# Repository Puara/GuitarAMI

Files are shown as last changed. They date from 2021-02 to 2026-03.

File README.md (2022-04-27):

# GuitarAMI

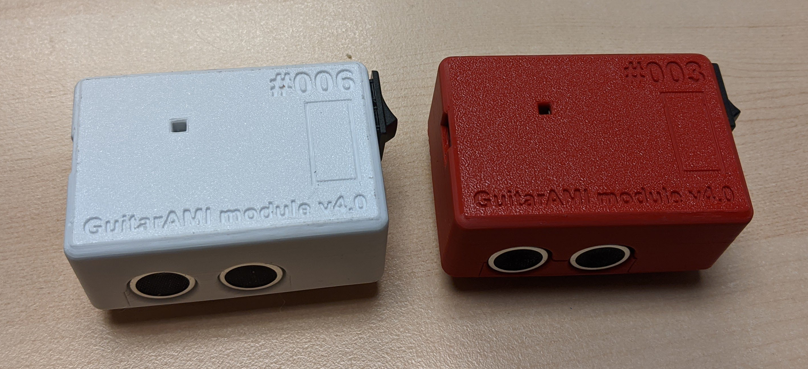
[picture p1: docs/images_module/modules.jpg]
Modules


The GuitarAMI is an Augmented Musical Instrument (AMI) using an acoustic guitar. The AMI is part of the [Puara](https://github.com/Puara) framework.

[GuitarAMI module - user guide](./docs/Module_user_guide.md)

## Building instructions

[GuitarAMI module](./docs/building_instructions_guitar_module.md)

## Description

Acoustic musical instruments, although very versatile, have intrinsic sonic limitations due to their construction characteristics. For the classical nylon strings guitar, these restrictions include short sustain and the lack of sound intensity control after the attack.

The GuitarAMI uses sensors installed non-invasively in classical guitars to generate data from gestures that control algorithms to overcome these limitations, providing new possibilities of expression for the performer.

### More Info on the instrument and the research

[https://www.edumeneses.com](https://www.edumeneses.com)

[http://www-new.idmil.org/project/guitarami/](http://www-new.idmil.org/project/guitarami/)

## Licensing

The code in this project is licensed under the MIT license, unless otherwise specified within the file.

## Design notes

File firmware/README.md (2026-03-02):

# OSC-Send

This template demonstrates how to use Puara modules to send OSC messages from the device.

Please refer to CNMAT's OSC repository on Github for more details on OSC.

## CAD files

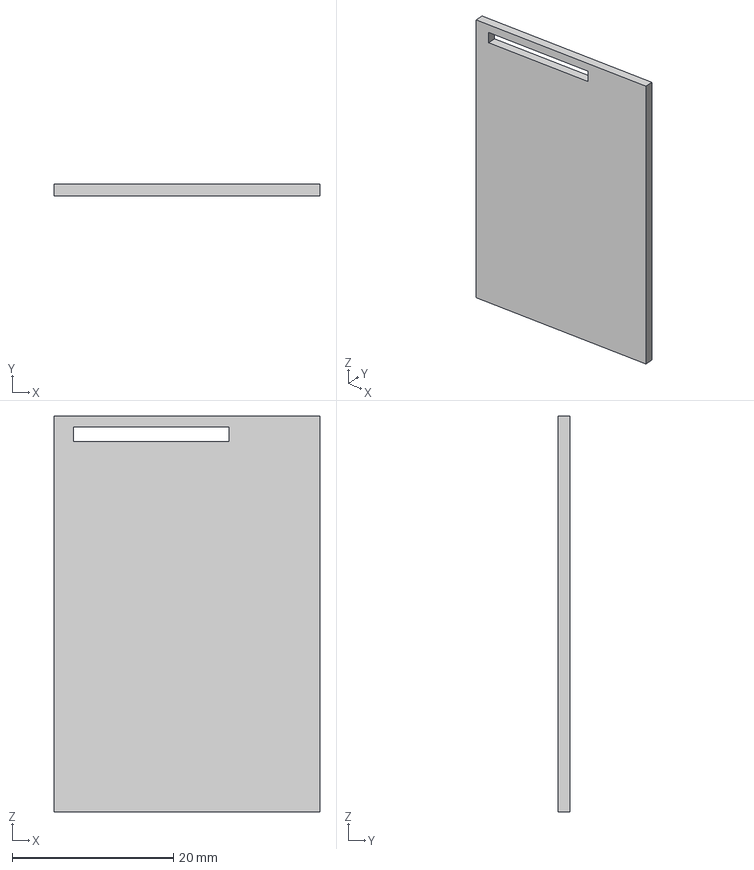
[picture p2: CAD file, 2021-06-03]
3D_printed_enclosure/GuitarAMI_module_XXX_TinyPICO_RCWL1601_battery_bed_top.step
33.0 x 1.50 x 49.1 mm

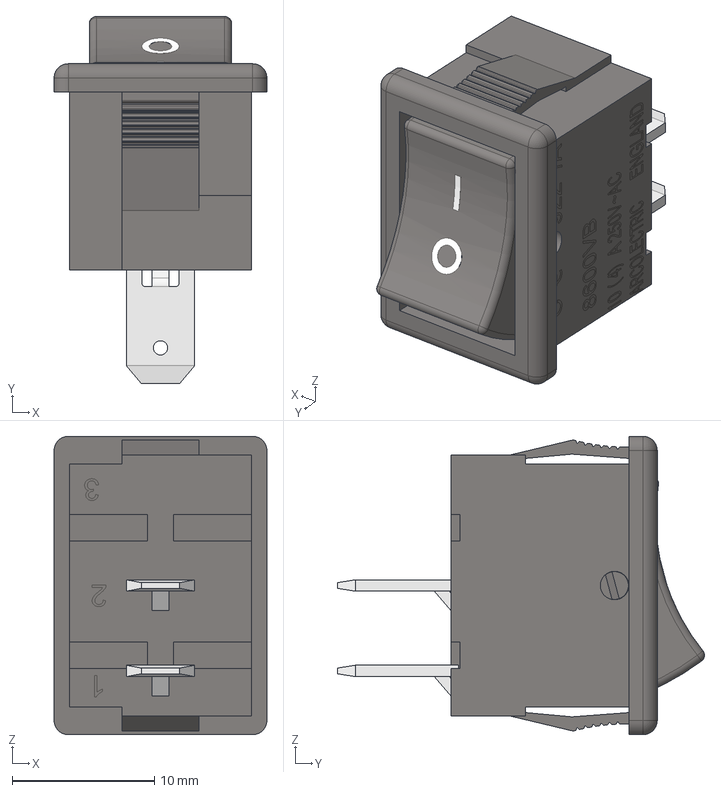
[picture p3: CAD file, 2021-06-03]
3D_printed_enclosure/parts/H8600V.step
14.9 x 25.8 x 20.9 mm
Housing
Rocker
Terminal x 2

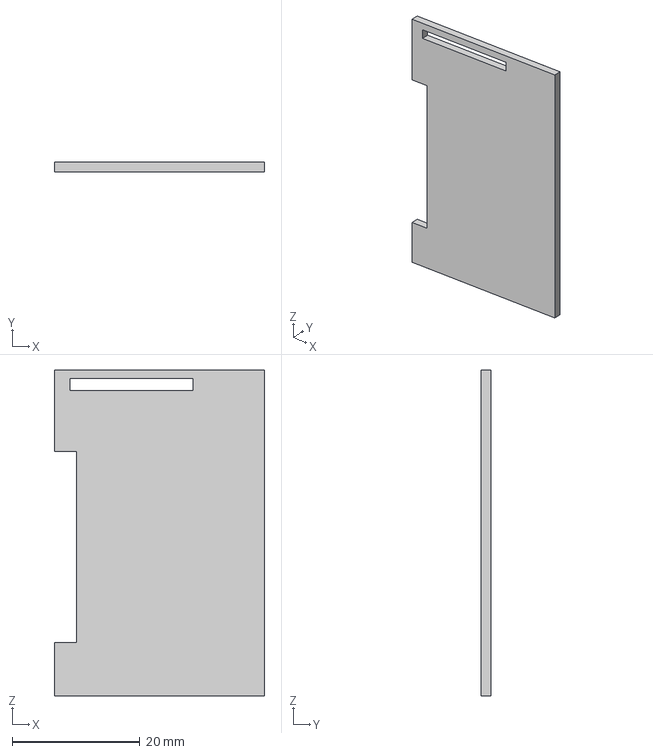
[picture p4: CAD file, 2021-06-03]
3D_printed_enclosure/GuitarAMI_module_XXX_TinyPICO_RCWL1601_battery_bed_bottom.step
33.0 x 1.50 x 51.1 mm

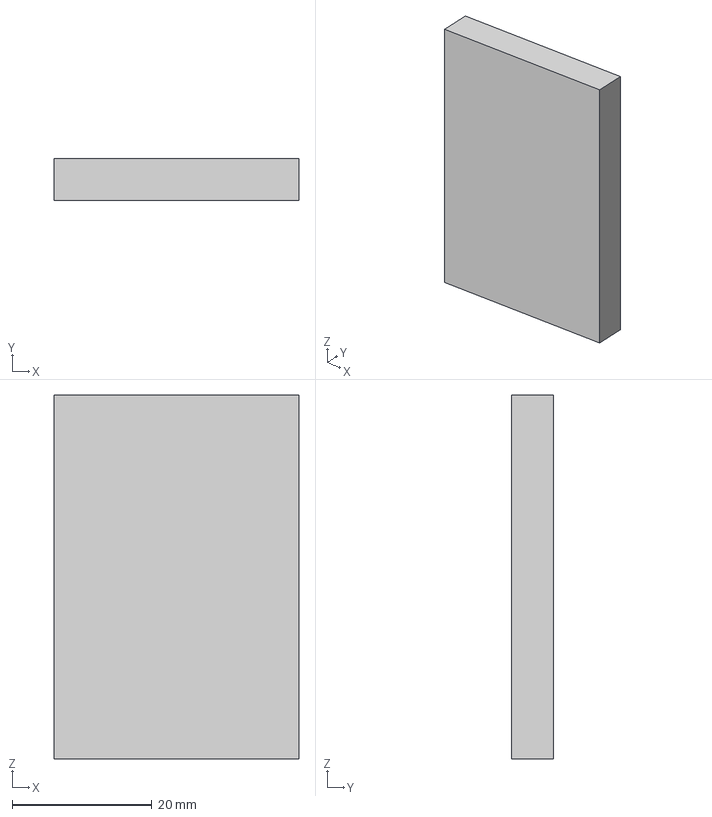
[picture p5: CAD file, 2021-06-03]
3D_printed_enclosure/parts/battery.step
35.0 x 6.00 x 52.0 mm

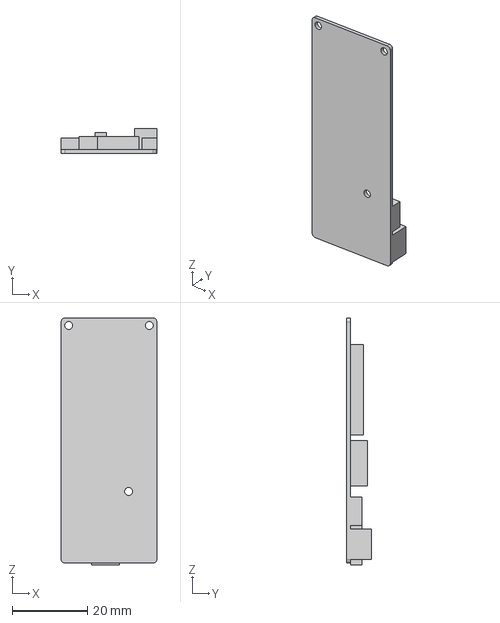
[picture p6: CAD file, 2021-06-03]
3D_printed_enclosure/parts/Wemos D32 Pro.step
25.4 x 6.50 x 65.5 mm

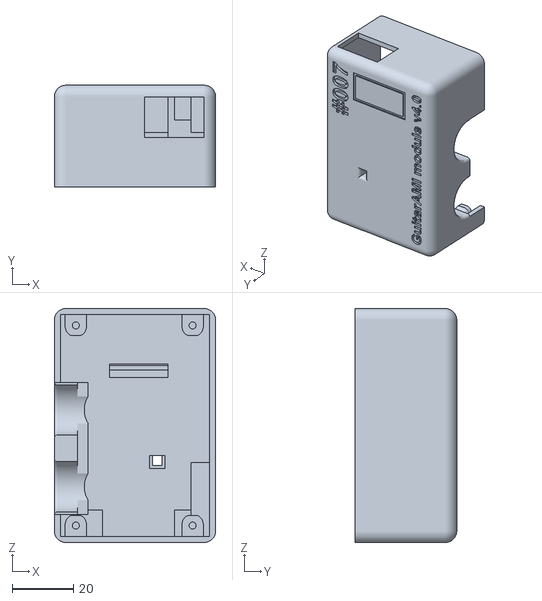
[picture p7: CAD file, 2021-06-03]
3D_printed_enclosure/GuitarAMI_module_007_TinyPICO_HCSR04+_box_top.stl
52.5 x 33.1 x 76.1

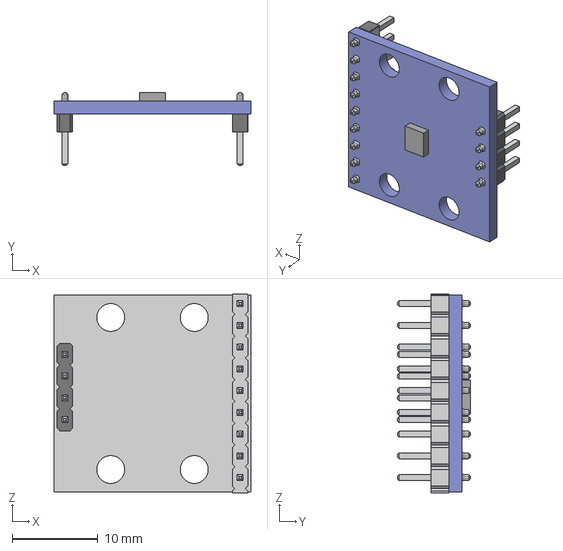
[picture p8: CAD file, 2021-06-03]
3D_printed_enclosure/parts/LSM9DS1.step
23.0 x 8.55 x 23.2 mm

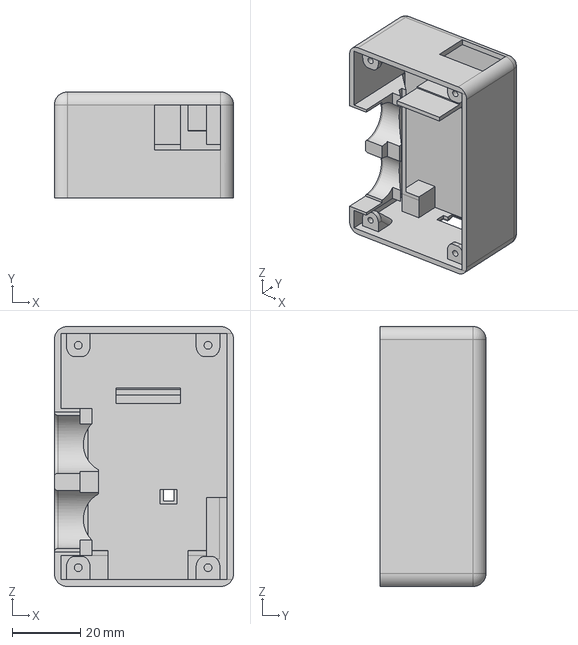
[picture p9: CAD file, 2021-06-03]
3D_printed_enclosure/GuitarAMI_module_XXX_TinyPICO_RCWL1601_box_top.step
52.5 x 31.1 x 76.1 mm

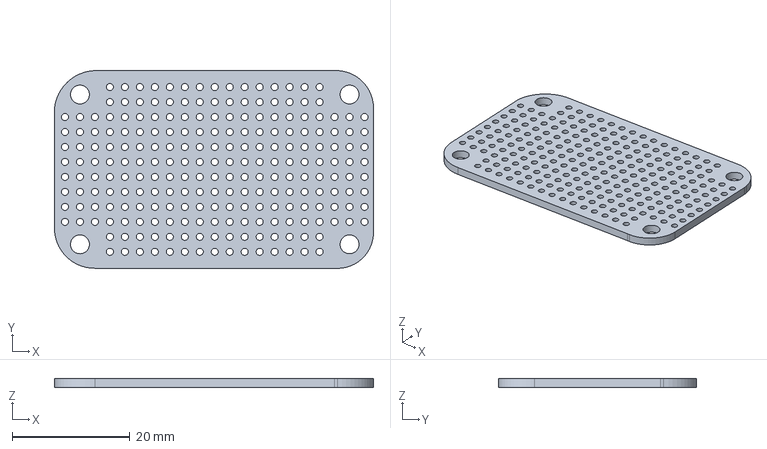
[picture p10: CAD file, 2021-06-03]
3D_printed_enclosure/parts/adafruit permaproto smalls.step
54.1 x 33.5 x 1.50 mm
Board
ALTOIDSSMALLS

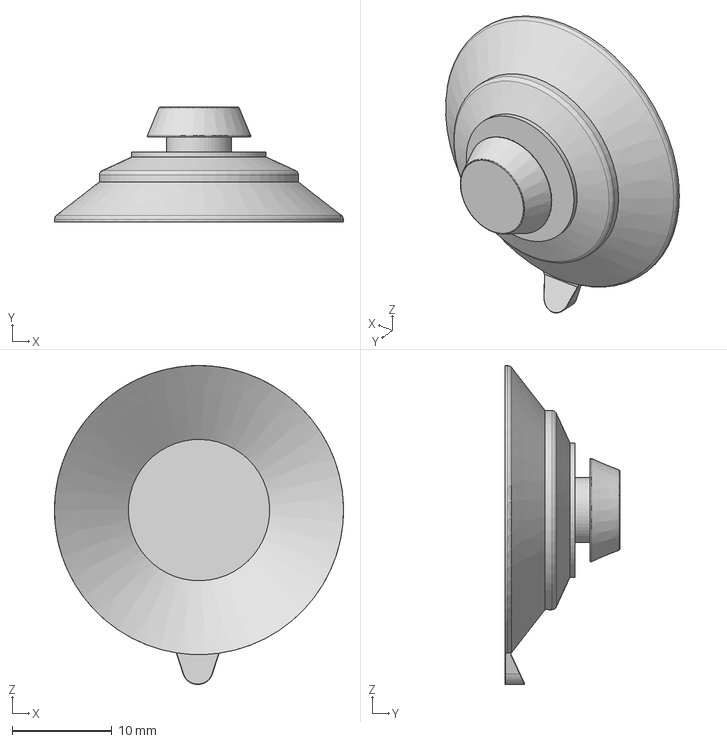
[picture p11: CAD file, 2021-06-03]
3D_printed_enclosure/parts/suction_cup_S-17647.step
29.0 x 11.5 x 32.0 mm

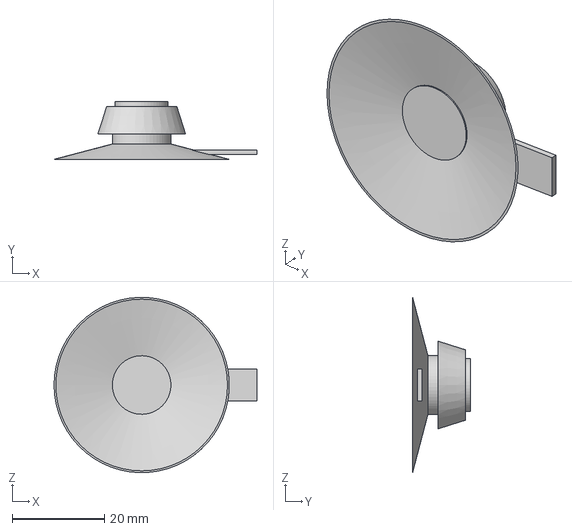
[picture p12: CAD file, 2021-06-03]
3D_printed_enclosure/parts/suction_cup_gitano.step
44.0 x 12.5 x 38.0 mm

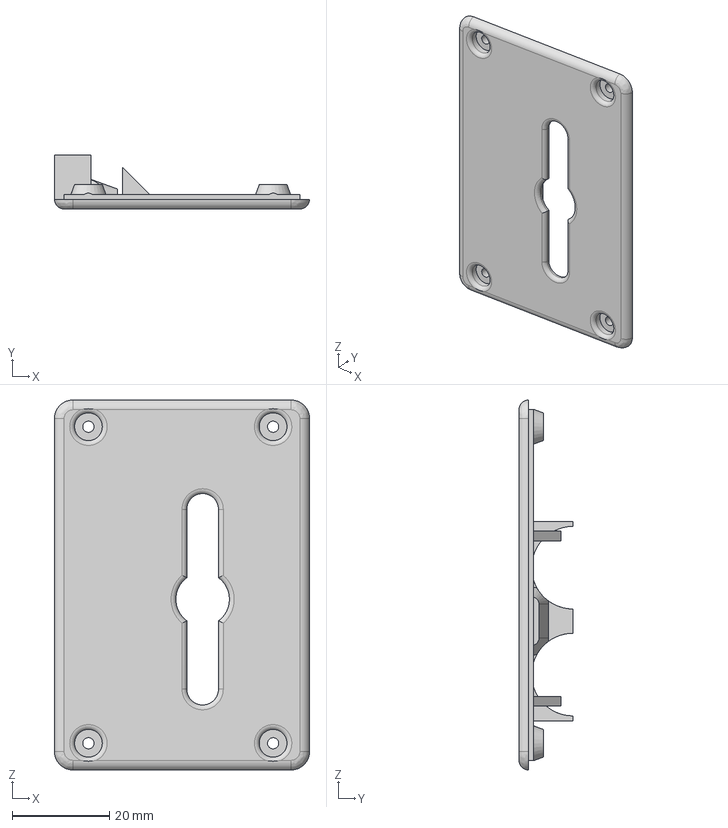
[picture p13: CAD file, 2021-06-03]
3D_printed_enclosure/GuitarAMI_module_XXX_TinyPICO_RCWL1601_box_bottom.step
52.5 x 11.1 x 76.1 mm

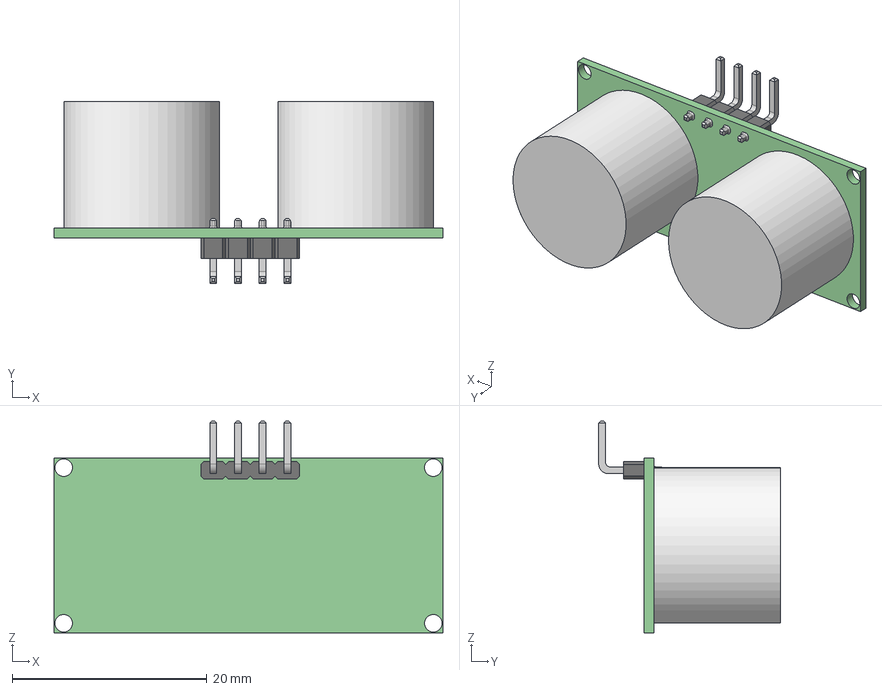
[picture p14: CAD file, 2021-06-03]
3D_printed_enclosure/parts/RCWL1601.step
40.0 x 18.7 x 21.8 mm

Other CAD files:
3D_printed_enclosure/GuitarAMI_module_XXX_TinyPICO_HCSR04+_battery_bed_bottom.stl
3D_printed_enclosure/GuitarAMI_module_003_TinyPICO_RCWL1601_box_top.stl
3D_printed_enclosure/GuitarAMI_module_006_TinyPICO_RCWL1601_box_top.stl
3D_printed_enclosure/GuitarAMI_module_005_TinyPICO_RCWL1601_box_top.stl
3D_printed_enclosure/GuitarAMI_module_XXX_TinyPICO_HCSR04+_battery_bed_top.stl
3D_printed_enclosure/GuitarAMI_module_XXX_TinyPICO_HCSR04+_box_bottom.stl
3D_printed_enclosure/GuitarAMI_module_XXX_TinyPICO_RCWL1601_battery_bed_bottom.stl
3D_printed_enclosure/GuitarAMI_module_XXX_TinyPICO_RCWL1601_battery_bed_top.stl
3D_printed_enclosure/GuitarAMI_module_XXX_TinyPICO_RCWL1601_box_bottom.stl
3D_printed_enclosure/GuitarAMI_module_XXX_TinyPICO_RCWL1601_box_top.stl

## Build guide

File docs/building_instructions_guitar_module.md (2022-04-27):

# How to build: GuitarAMI guitar module

## BOM

| Qty | Description | Online Reference |
| --- |:---|:--- |
| 1 | Rocker Switch | https://www.digikey.ca/en/products/detail/bulgin/H8600VBACN/9598449 |
| 1 | Small Suction Cups without Hooks | https://www.uline.ca/Product/Detail/S-17647/Store-Supplies/Suction-Cups-without-Hooks-Small |
| 1 | Perma-Proto Small Mint Tin Size Breadboard PCB | https://www.adafruit.com/product/1214 |
| 1 | Ultrasonic Distance Sensor - 3V compatible - RCWL-1601 | https://www.adafruit.com/product/4007 |
| 1 | TinyPICO - ESP32 Development Board | https://www.adafruit.com/product/4335 |
| 1 | 3.7V 2000mAh LiPo Rechargeable Battery | https://www.adafruit.com/product/2011 |
| 1 | LSM9DS1 nine-axis Sensor Module 9-axis IMU | https://www.sparkfun.com/products/13284 |

## Instructions

Start with the Perma-Proto Breadboard and solder all required connections according to the picture.

The IMU uses I2C, and it will be connected on rows 11-14 (breadboard) pins.
The TinyPico I2C (SDA and SCL) connections will be soldered on rows 3 and 2 of the breadboard (opposite side).

The ultrasonic sensor trigger and echo will be connected on rows 9 and 8 on the breadboard.
The TinyPico pins for that will be connected on rows 4 and 5 on the breadboard (same side).

The remaining jumper wires are for VCC and ground.

> :warning: **The TinyPico cannot reliably provide 5V when powered from battery**: Make sure the chosen ultrasonic sensor operates with 3.3V!

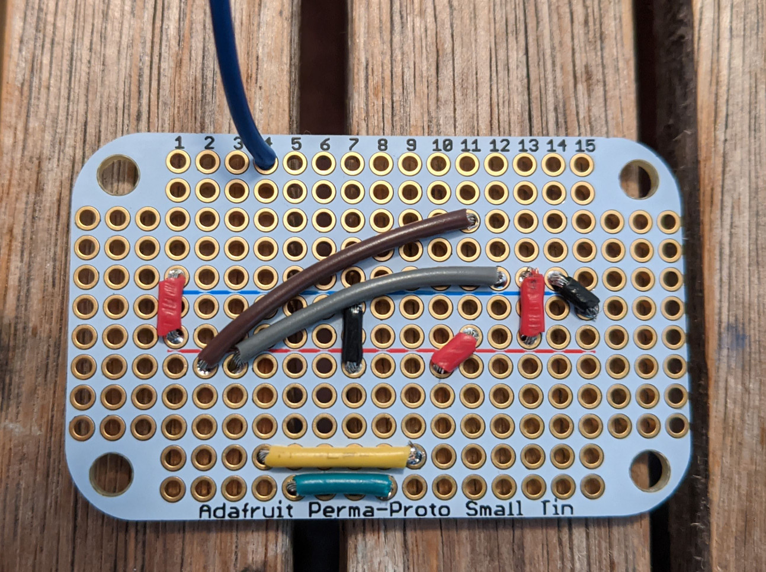
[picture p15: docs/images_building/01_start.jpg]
Start


Proceed by soldering the IMU:

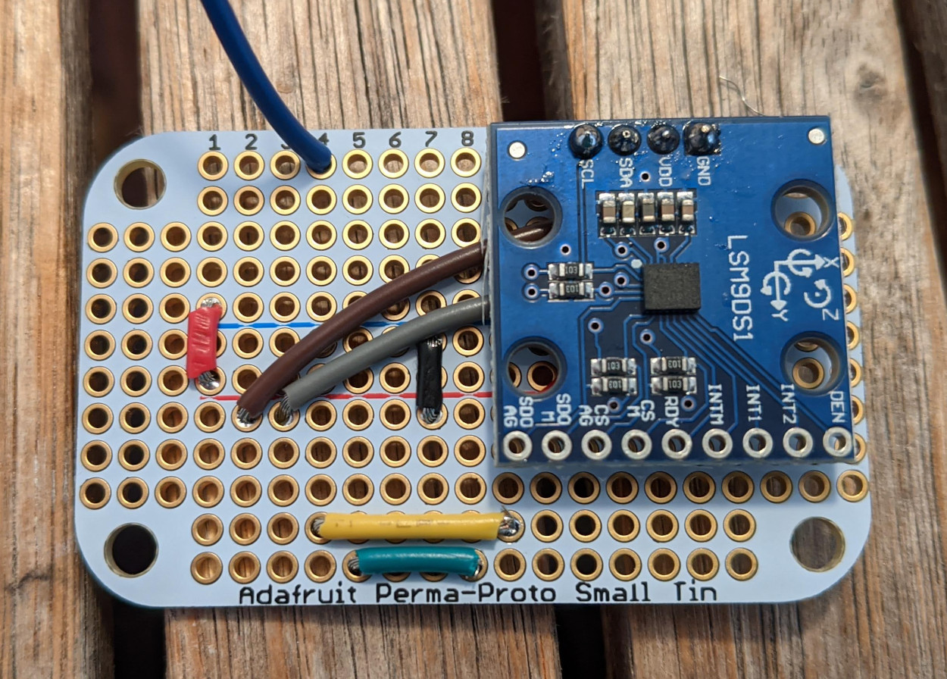
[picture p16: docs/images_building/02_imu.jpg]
IMU


Then the ultrasonic sensor. Note that the sensor is soldered "upside down".

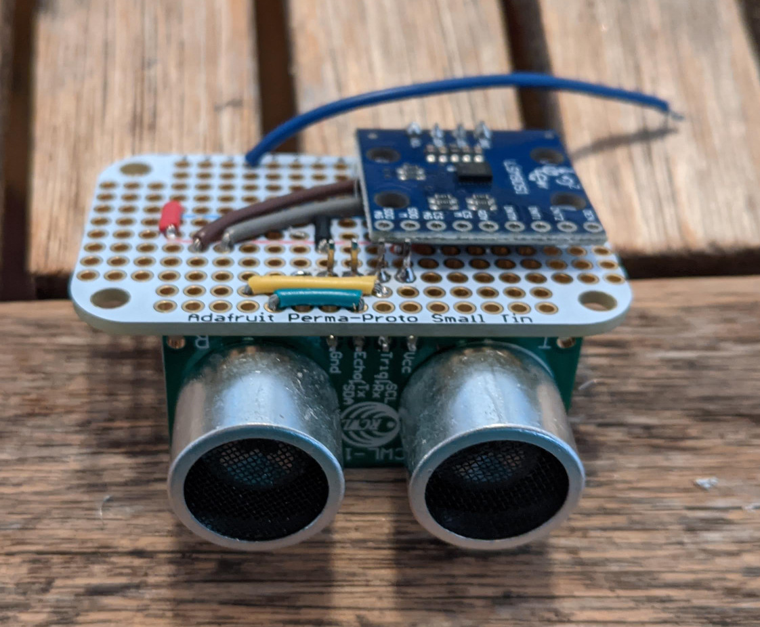
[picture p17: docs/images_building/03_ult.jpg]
Ultrasonic


Start preparing the TinyPico: set the header pins according to the picture below:

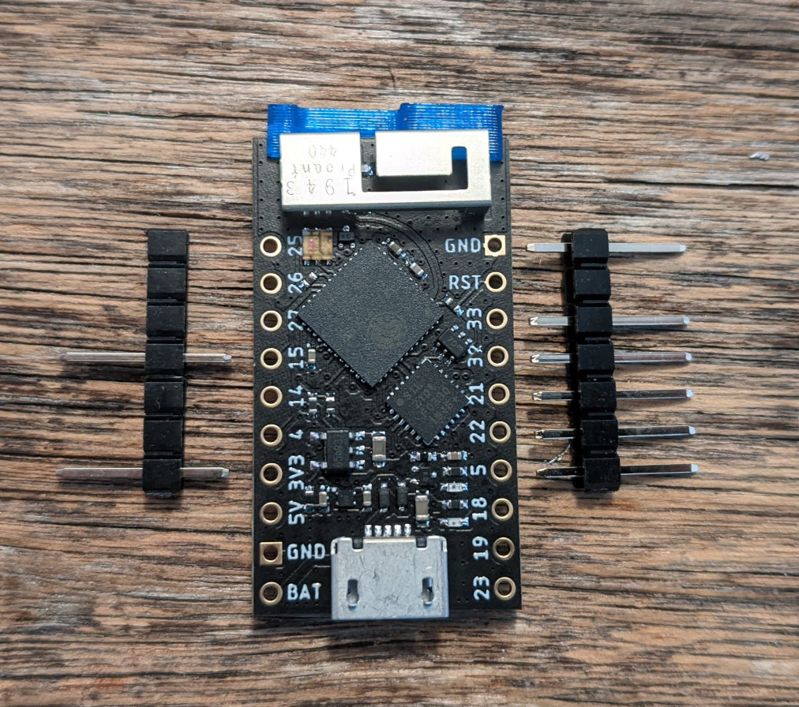
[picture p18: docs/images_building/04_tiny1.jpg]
TinyPico part 1 Tiny Pico part 1


Solder the pins on the TinyPico...

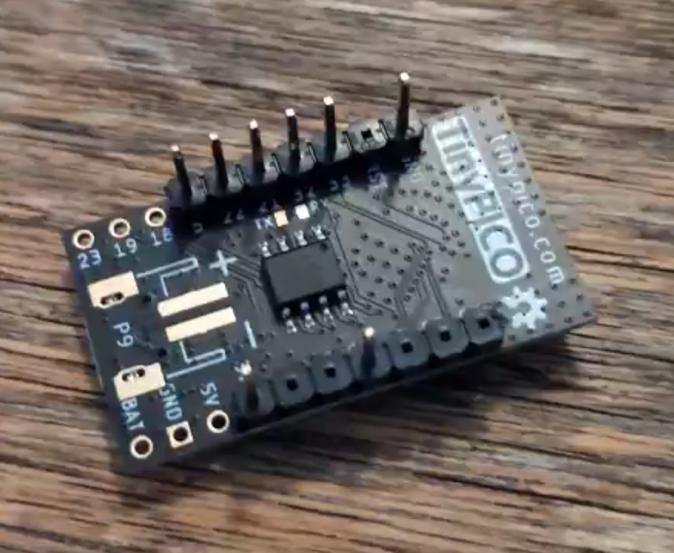
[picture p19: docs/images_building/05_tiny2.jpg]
TinyPico part 2 Tiny Pico part 2


... and the TinyPico to the breadboard according to the picture below.
Note that the USB connector must be aligned with the end of the breadboard.
That means some overlapping with the IMU is required.

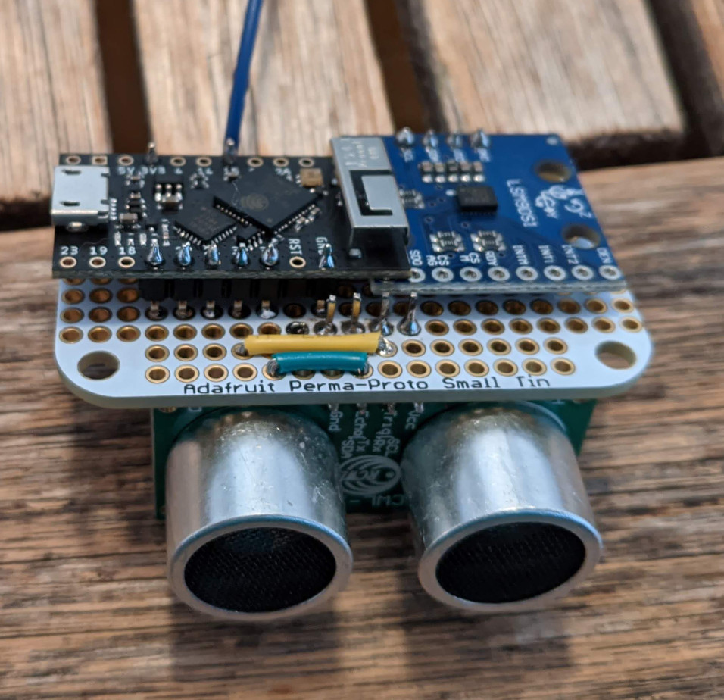
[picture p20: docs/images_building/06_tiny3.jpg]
TinyPico part 3 Tiny Pico part 3


Start preparing the touch sensor: a piece of copper tape and some wiring:

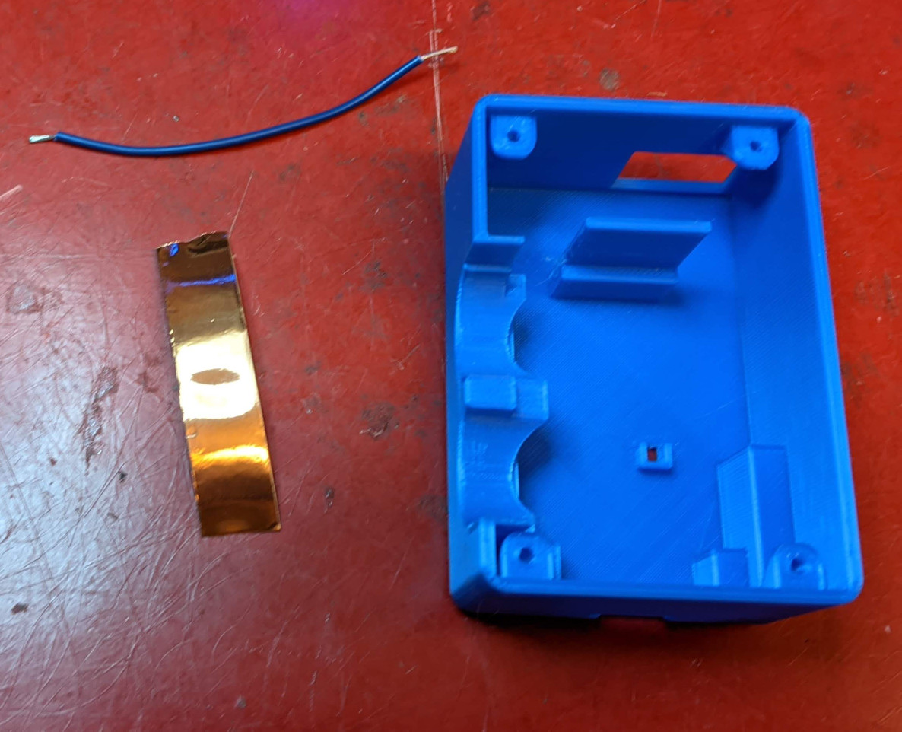
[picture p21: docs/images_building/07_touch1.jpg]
Touch part 1


Tape and solder according to the picture:

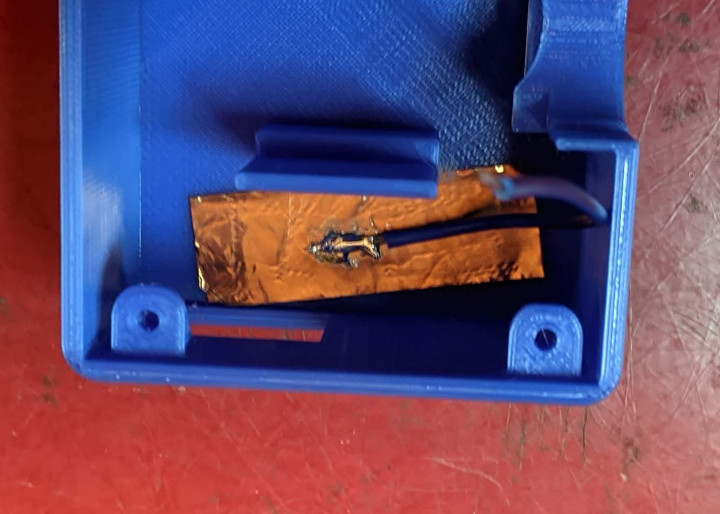
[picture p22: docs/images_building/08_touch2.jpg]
Touch part 2


Protect the copper tape to prevent sensor acquisition problems:

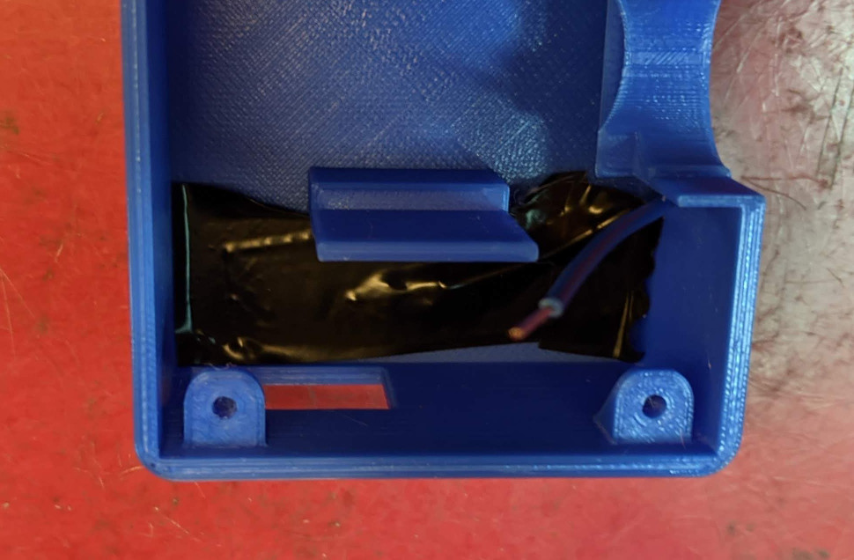
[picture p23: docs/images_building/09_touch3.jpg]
Touch part 3


Lastly, prepare the rocker switch:

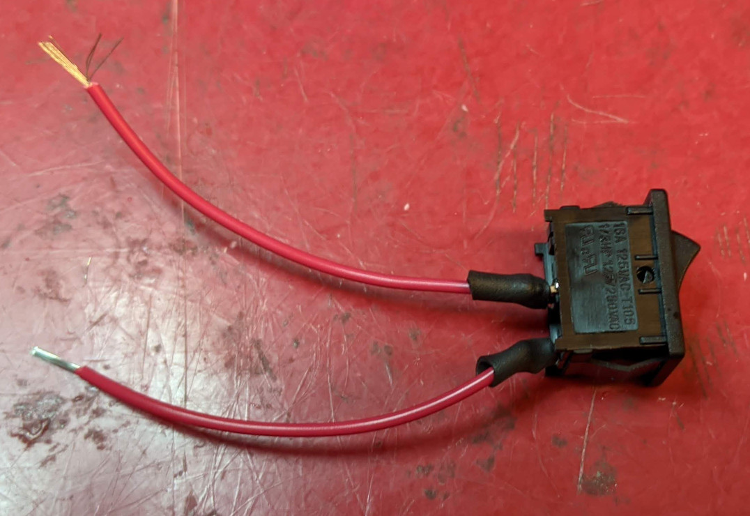
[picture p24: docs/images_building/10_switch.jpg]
Rocker Switch


Add the 3D printed enclosure and assemble everything together according to the pictures below.
The battery caps protect the breadboard and battery, and it is recommended to use the bottom cap.
The top cap can be used to prevent the battery to shake inside the module, if needed.

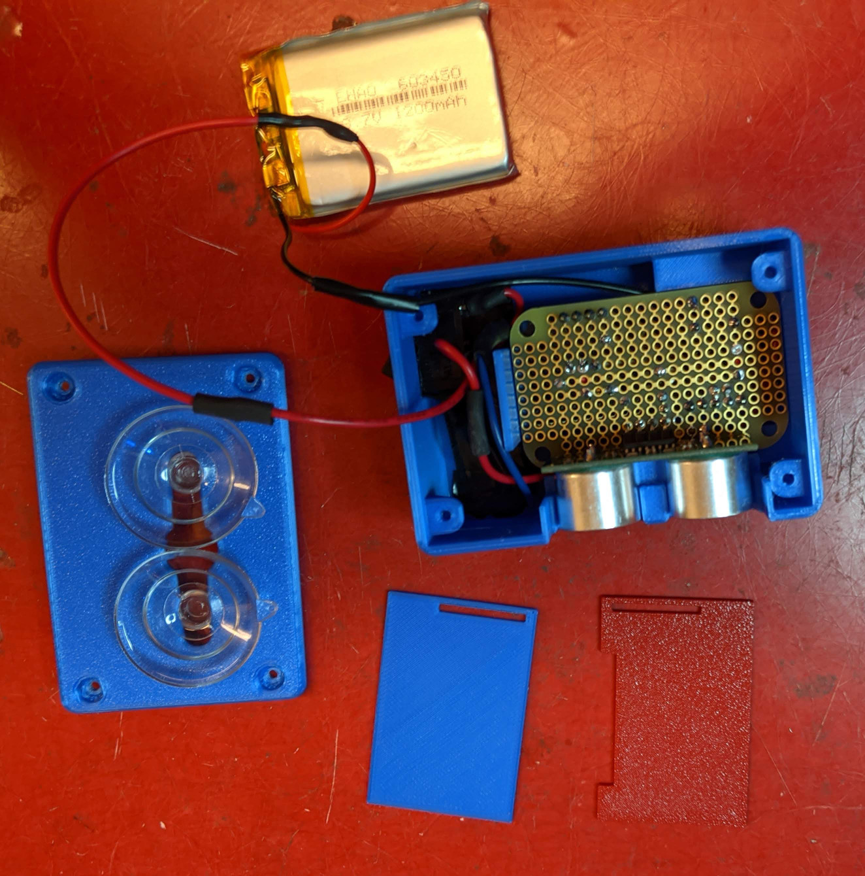
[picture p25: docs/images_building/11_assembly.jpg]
Putting everything together part 1


The top cap can be used to prevent the battery to shake inside the module, if needed.

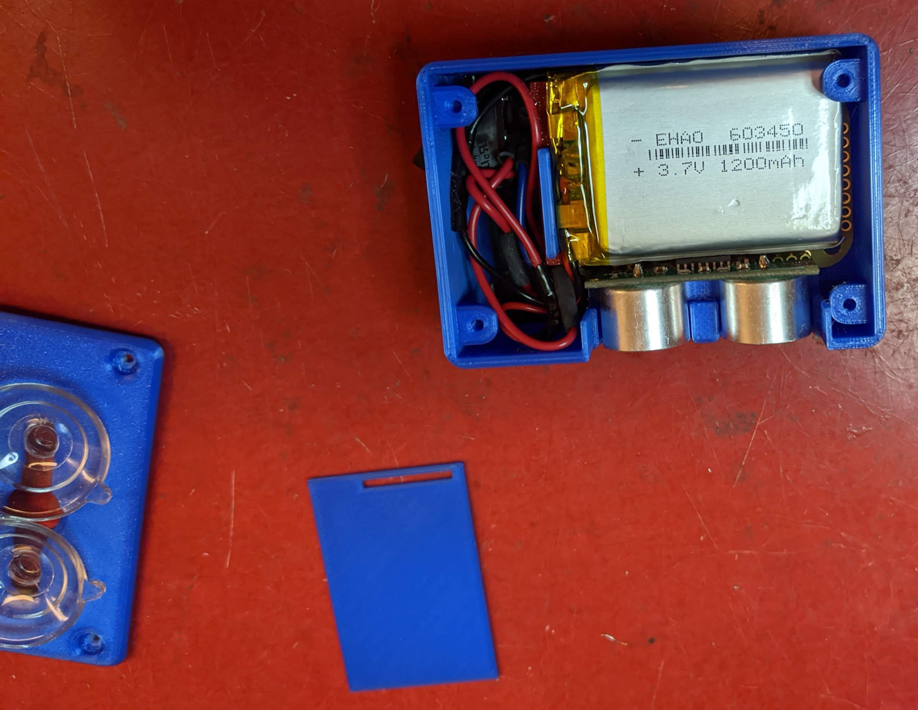
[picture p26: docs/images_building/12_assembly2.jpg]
Putting everything together part 2


Done! Have fun.

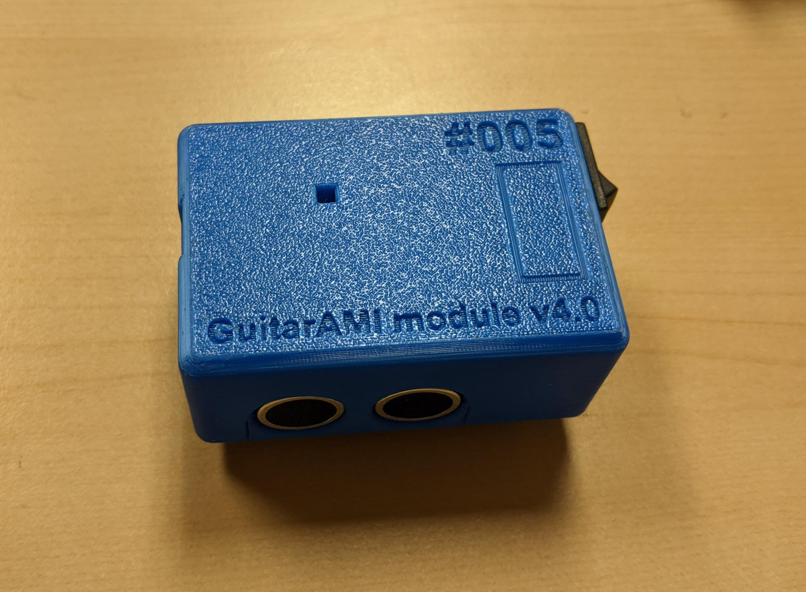
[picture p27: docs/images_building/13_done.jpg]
Done!


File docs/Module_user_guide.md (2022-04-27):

# GuitarAMI Module user guide

Modules

- [GuitarAMI Module user guide](#guitarami-module-user-guide)
  - [Usage instructions](#usage-instructions)
    - [Operation modes](#operation-modes)
    - [Setup](#setup)
    - [LED indicator](#led-indicator)
    - [Charging your module](#charging-your-module)
  - [OSC namespaces](#osc-namespaces)
  - [MIDI messages](#midi-messages)
  - [Pure Data test patch](#pure-data-test-patch)
  - [Updating module firmware](#updating-module-firmware)
  - [Information](#information)

## Usage instructions

### Operation modes

The module can operate in 3 different modes:

- OSC-STA mode: The module becomes a WiFi client (station mode) and will send OSC messages to the addresses/ports configured on the setup page. Both the module and recipient must be connected to the same network.
- OSC-AP mode: The module creates its own WiFi network (access point) and will send OSC messages to the addresses/ports configured on the setup. The AP created uses credentials configured on the setup page and recipient must be connected to the module's network. The AP's name is created using the instrument's name, e.g, *GuitarAMI_module_XXX*. The default password is `mappings`.
- MIDI mode: The module behaves as a BLE MIDI device, and can be used as a wireless midi controller.

### Setup

The module also has a special setup mode. To access the mode, hold the capacitive touch for 5 seconds. The module will reboot and enter the setup mode. You can access the setup page using 2 different methods:

- Using the module's AP:
  - Access the AP (created using the instrument's name, e.g, *GuitarAMI_module_XXX* and previously stored password)
  - In a new browser window, type either [http://GuitarAMI_module_XXX.local/](http://GuitarAMI_module_XXX.local/) (replace the XXX by your module's ID) or the IP address (if known), e.g., *192.168.0.100*
- Using the current network (STA):
  - In a new browser window, type either [http://GuitarAMI_module_XXX.local/](http://GuitarAMI_module_XXX.local/) (replace the XXX by your module's ID) or the IP address (if known), e.g., *192.168.0.100*

The setup options include:

- Network:
  - SSID: network SSID for STA mode (will autofill with current SSID)
  - SSID Password: password for STA mode network (will autofill with current password)
- GuitarAMI module password:
  - New password: type password for AP and setup modes (leave it blank if you want to keep the same password)
  - Retype new password: retype password for AP and setup modes (leave it blank if you want to keep the same password)
- Operation mode:
  - STA (station), AP (access point), MIDI
- OSC send settings:
  - Primary IP: first IP address to send OSC messages (STA and AP modes)
  - Primary port: first port to send OSC messages (STA and AP modes)
  - Secondary IP: second IP address to send OSC messages (STA and AP modes)
  - Secondary port: second port to send OSC messages (STA and AP modes)
- Scan for networks: open a secondary page with the scanned networks in the area. This list may not be complete, and it's necessary to fill the SSID (for STA mode) manually on the setup page (you can copy/paste the SSID from the scan page)
- SAVE button: click to save the current configuration

The setup page also contains extra information about the module: Current SSID, Current IP address (STA), Access Point IP, Station (STA) MAC address, Access Point MAC address, module ID (serial #), module author, Institution, and Firmware version.

To exit the setup mode, click on `Close and Reboot`. The module will reboot into the chosen operation mode.

### LED indicator

The GuitarAMI module has a built-in LED to indicate status and battery level.

- For the modules using the TinyPICO (with RGB LED):
  - Low battery indicator: fast blink (flickering) in Red
  - Mode indicator (color):
    - STA: Dodger Blue
    - AP: Lime
    - MIDI: Magenta
    - Setup: Dark Orange
  - Connection indicator: the LED will blink slowly when connected, while it will cycle-fade when disconnected
  - Battery Charge: Orange (on secondary LED close to USB port)
  - USB Power connection: Red (on secondary LED close to USB port)
  - Error: if everything goes wrong it cycles through all colors (rainbow panic)

- For the older modules using the Wemos D32 Pro (with blue LED next to the USB port):
  - Low battery indicator: fast blink (flickering)
  - Setup mode: the LED will be always ON
  - Connection indicator: the LED will blink slowly when connected, while it will cycle-fade when disconnected

### Charging your module

To charge the module, connect any 5V USB power supply to the micro-USB port. A red light will indicate that the module is charging.

IMPORTANT: The module needs to be turned ON to charge!
{: .alert .alert-warning}

## OSC namespaces

- continuous:
  - /GuitarAMI_module_XXX/ult [int] (in mm)
  - /GuitarAMI_module_XXX/accl [float] [float] [float] (in m/s^2)
  - /GuitarAMI_module_XXX/gyro [float] [float] [float] (in radians per second)
  - /GuitarAMI_module_XXX/magn [float] [float] [float] (in uTesla)
  - /GuitarAMI_module_XXX/quat [float] [float] [float]
- discrete:
  - /GuitarAMI_module_XXX/tap [0 or 1]
  - /GuitarAMI_module_XXX/dtap [0 or 1]
  - /GuitarAMI_module_XXX/ttap [0 or 1]
  - /GuitarAMI_module_XXX/battery [int] (percentage)
- Instrument:
  - /GuitarAMI_module_XXX/ypr [float] [float] [float] (in degrees)
  - /GuitarAMI_module_XXX/jab [float] [float] [float]
  - /GuitarAMI_module_XXX/shake [float] [float] [float]
  - /GuitarAMI_module_XXX/count [int]
  - /GuitarAMI_module_XXX/ultTrig [int] [0 or 1]

## MIDI messages

- continuous:
  - CC 20: ultrasonic sensor scaled from 0 to 300 mm
  - CC 21: absolute X-axis acceleration, scaled from 0 to 50 m/s^2 (~5.1 gs)
  - CC 22: absolute Y-axis acceleration, scaled from 0 to 50 m/s^2 (~5.1 gs)
  - CC 23: absolute Z-axis acceleration, scaled from 0 to 50 m/s^2 (~5.1 gs)
  - CC 24: absolute X-axis angular velocity (gyroscope), scaled from 0 to 25 rad/s
  - CC 25: absolute Y-axis angular velocity (gyroscope), scaled from 0 to 25 rad/s
  - CC 26: absolute Z-axis angular velocity (gyroscope), scaled from 0 to 25 rad/s
  - CC 27: yaw, scaled from -180 to 180 degrees
  - CC 28: pitch, scaled from -180 to 180 degrees
  - CC 29: roll, scaled from -180 to 180 degrees
  - CC 85: shake X
  - CC 86: shake Y
  - CC 87: shake Z
  - CC 102: jab X
  - CC 103: jab Y
  - CC 104: jab Z
- discrete:
  - CC 30: tap [0 or 127]
  - CC 31: double tap [0 or 127]
  - CC 14: triple tap [0 or 127]
  - CC 15: touch count starting from 0
  - CC 89: Ultrasonic trigger [0 or 127]

## Pure Data test patch

There is an GuitarAMI module [Pure Data](http://puredata.info/) test patch for OSC and MIDI that can be downloaded [directly from the module](/GuitarAMI_module.pd) ([GuitarAMI_module.pd](/GuitarAMI_module.pd)). Users can check if all data is reaching the destination and the interval between messages.

## Updating module firmware

To update your firmware, please follow the following steps:
  
- Download the new firmware or spiffs file (.bin) provided by the module's author
- Enter the [Setup mode](#setup)
- In a new browser window, type either [http://GuitarAMI_module_XXX.local/update](http://GuitarAMI_module_XXX.local/update) (replace the XXX by your module's ID) or the IP address (if known), e.g., [192.168.0.100/update](192.168.0.100/update)
- Click on `choose file` and select the apropriate file. Check if the filename is correct (next to the button)
- Click on `Update Firmware` or `Update SPIFFS` according to the chosen file
- **DO NOT turn the module OFF during the process**. Wait until the module reboot itself: the update page will be unavailable, and the module will enter setup mode again. You can then access the [setup page](#setup) and click on `Close and reboot`

## Information

GuitarAMI (classical guitar) Module - WiFi(OSC) + MIDI
[Input Devices and Music Interaction Laboratory (IDMIL)](http://www.idmil.org/)
[Centre of Interdisciplinary Research In Music Media and Technology (CIRMMT)](http://www.cirmmt.org/)
February 2021 by [Edu Meneses](http://www.edumeneses.com/)

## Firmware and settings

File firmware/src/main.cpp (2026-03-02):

//****************************************************************************//
// GuitarAMI Module                                                           //
// Input Devices and Music Interaction Laboratory (IDMIL), McGill University  //
// Edu Meneses (2026) - https://www.edumeneses.com                            //
// Created using the Puara templates:                                         //
//                https://github.com/Puara/puara-module-templates             //
//****************************************************************************//

#include "Arduino.h"
#include "OSCBundle.h"
#include "OSCMessage.h"
#include "OSCTiming.h"
#include "WiFiUdp.h"
#include "esptouch.h"
#include "led.h"
#include "puara.h"
#include "puara/gestures.h"
#include "puara/structs.h"
#include "ult.h"

#include <iostream>

#define ASSUMED_EMPTY_BATTERY_VOLTAGE 2.9
#define ASSUMED_FULL_BATTERY_VOLTAGE 4.15

// (Un)comment the proper module for your system (LSM9DS1 or BNO080).
#define imu_LSM9DS1
// #define imu_BNO080

#ifdef imu_BNO080
#include "bno080.h"
Imu_BNO080 imu;
#endif
#ifdef imu_LSM9DS1
#include "lsm9ds1.h"
Imu_LSM9DS1 imu;
#endif

Led led;
Puara puara;
Touch touch;
WiFiUDP Udp;

struct Sensors {
  int battery;
  int touch;
  int ultDistance;
  int ultTrigger;
};

struct led_variables {
  int ledValue = 0;
  uint8_t color = 0;
};

Sensors sensors;
led_variables led_var;

puara_gestures::Button button(&sensors.touch);
puara_gestures::Coord3D puaraYPR;
puara_gestures::Imu9Axis puaraIMU;
puara_gestures::Jab3D jab(&puaraIMU.accl);
puara_gestures::Quaternion puaraQuat;
puara_gestures::Shake3D shake(&puaraIMU.accl);

std::string oscIP{};
int oscPort{};
std::string osc_prefix{};

// Pin definitions
struct Pin {
  int led;     // Built In LED pin
  int touch;   // Capacitive touch pin
  int battery; // To check battery level (voltage)
  int ultTrig; // connects to the trigger pin on the distance sensor
  int ultEcho; // connects to the echo pin on the distance sensor
};

#ifdef ARDUINO_LOLIN_D32_PRO
#define ADC12BIT_MAX 4095.0
#define VOLTAGE_DIVIDER_RATIO 7.445
Pin pin{5, 15, 35, 32, 33};
#elif defined(ARDUINO_TINYPICO)
Pin pin{5, 4, 35, 32, 33};
#include "TinyPICO.h"
TinyPICO tinypico = TinyPICO();
#endif

//////////////////////////////////
// Battery struct and functions //
//////////////////////////////////

struct BatteryData {
  unsigned long timer = 0;
  float value = 0.0f;
  unsigned int percentage = 0;
  unsigned int lastPercentage = 0;
  int interval = 1000;         // ms between readings
  int queueAmount = 10;        // # of samples to average
  std::deque<int> filterArray; // history buffer
};

static BatteryData battery;
void readBattery();
void batteryFilter();

//////////////////////////////////////////////
// Updates when settings saved in webserver //
//////////////////////////////////////////////
void onSettingsChanged() {
  Udp.begin(puara.getVarNumber("localPORT"));
  oscIP = puara.getVarText("oscIP");
  oscPort = puara.getVarNumber("oscPORT");
  touch.setSensitivity(std::round(puara.getVarNumber("touch_sensitivity")));
}

///////////
// setup //
///////////

void setup() {
#ifdef Arduino_h
  Serial.begin(115200);
#endif

  puara.start();
  Udp.begin(puara.getVarNumber("localPORT"));
  oscIP = puara.getVarText("oscIP");
  oscPort = puara.getVarNumber("oscPORT");

  puara.set_settings_changed_handler(onSettingsChanged);

  osc_prefix = "/" + puara.dmi_name();

#ifdef ARDUINO_LOLIN_D32_PRO // LED init for WEMOS boards
  ledcSetup(0, 5000, 8);
  ledcAttachPin(pin.led, 0);
#endif

  std::cout << "    Initializing capacitive touch sensor... ";
  touch.setSensitivity(std::round(puara.getVarNumber("touch_sensitivity")));
  if (touch.initTouch()) {
    std::cout << "done" << std::endl;
  } else {
    std::cout << "capacitive touch sensor initialization failed!" << std::endl;
  }

  std::cout << "    Initializing ultrasonic sensor... ";
  if (initUlt(pin.ultTrig, pin.ultEcho)) {
    std::cout << "done" << std::endl;
  } else {
    std::cout << "ultrasonic sensor initialization failed!" << std::endl;
  }

  std::cout << "    Initializing IMU... ";
  if (imu.initIMU()) {
    std::cout << "done" << std::endl;
  } else {
    std::cout << "IMU initialization failed!" << std::endl;
  }

  Serial.println();
  Serial.println("Edu Meneses\nSociété des Arts Technologiques (SAT)\nIDMIL - "
                 "CIRMMT - McGill University");
  Serial.println();
}

void loop() {

  // Read Ultrasonic sensor distance
  readUlt();
  sensors.ultDistance = getUltDistance();

  // Read capacitive button
  touch.readTouch();
  sensors.touch =
      touch.getTouch() ? 1 : 0; // convert bool to int for OSC message
  button.update();
  // Read battery
  if (millis() - battery.interval > battery.timer) {
       battery.timer = millis();
       readBattery();
       batteryFilter();
     }

  // read IMU and update puara-gestures
  if (imu.dataAvailable()) {
    puaraIMU.accl.x = imu.getAccelX();
    puaraIMU.accl.y = imu.getAccelY();
    puaraIMU.accl.z = imu.getAccelZ();
    puaraIMU.gyro.x = imu.getGyroX();
    puaraIMU.gyro.y = imu.getGyroY();
    puaraIMU.gyro.z = imu.getGyroZ();
    puaraIMU.magn.x = imu.getMagX();
    puaraIMU.magn.y = imu.getMagY();
    puaraIMU.magn.z = imu.getMagZ();
    puaraQuat.w = imu.getQuatI();
    puaraQuat.x = imu.getQuatJ();
    puaraQuat.y = imu.getQuatK();
    puaraQuat.z = imu.getQuatReal();
    puaraYPR.x = imu.getYaw();
    puaraYPR.y = imu.getPitch();
    puaraYPR.z = imu.getRoll();
    jab.update();
    shake.update();
  }

  /*
   * Sending OSC messages.
   * This sends the sensor value to the defined OSC IP : port.
   */
  if (!oscIP.empty() && oscIP != "0.0.0.0") {

    OSCBundle bundle;
    osctime_t timetag;

    bundle.add((osc_prefix + "/IMU").c_str())
      .add(puaraIMU.accl.x).add(puaraIMU.accl.y).add(puaraIMU.accl.z);

    bundle.add((osc_prefix + "/gyro").c_str())
      .add(puaraIMU.gyro.x).add(puaraIMU.gyro.y).add(puaraIMU.gyro.z);

    bundle.add((osc_prefix + "/magn").c_str())
      .add(puaraIMU.magn.x).add(puaraIMU.magn.y).add(puaraIMU.magn.z);
    
    bundle.add((osc_prefix + "/quat").c_str())
      .add(puaraQuat.w).add(puaraQuat.x).add(puaraQuat.y).add(puaraQuat.z);

    bundle.add((osc_prefix + "/YPR").c_str())
      .add(puaraYPR.x).add(puaraYPR.y).add(puaraYPR.z);

    bundle.add((osc_prefix + "/ultrasonic").c_str())
      .add(static_cast<int32_t>(sensors.ultDistance));

    bundle.add((osc_prefix + "/touch").c_str())
      .add(touch.getValue());
    
    bundle.add((osc_prefix+"/button/press").c_str()).add(button.press);
    bundle.add((osc_prefix+"/button/hold").c_str()).add(button.hold);
    bundle.add((osc_prefix+"/button/pressTime").c_str()).add(button.pressTime);
    bundle.add((osc_prefix+"/button/tap").c_str()).add(button.tap);
    bundle.add((osc_prefix+"/button/doubleTap").c_str()).add(button.doubleTap);
    bundle.add((osc_prefix+"/button/tripleTap").c_str()).add(button.tripleTap);
    bundle.add((osc_prefix+"/button/count").c_str()).add(button.count);
    
    bundle.add(("/" + puara.dmi_name() + "/jab").c_str())
      .add(jab.x.current_value())
      .add(jab.y.current_value())
      .add(jab.z.current_value());
    
    bundle.add(("/" + puara.dmi_name() + "/shake").c_str())
      .add(shake.x.current_value())
      .add(shake.y.current_value())
      .add(shake.z.current_value());
    
    bundle.add(("/" + puara.dmi_name() + "/battery").c_str())
      .add(battery.percentage);

    Udp.beginPacket(oscIP.c_str(), oscPort);
    bundle.setTimetag(oscTime());
    bundle.send(Udp);
    Udp.endPacket();
    bundle.empty();
  }

  // Set LED - connection status and battery level
  #ifdef ARDUINO_LOLIN_D32_PRO
    if (battery.percentage < 10) {        // low battery - flickering
      led.setInterval(75);
      led_var.ledValue = led.blink(255, 50);
      ledcWrite(0, led_var.ledValue); // why is this at 0 but led pin is defined above...
    } else {
    // blinks when connected, cycle when disconnected
      if (puara.get_StaIsConnected()) { 
        led.setInterval(1000);
        led_var.ledValue = led.blink(255, 40);
        ledcWrite(0, led_var.ledValue);
      } else {
        led.setInterval(4000);
        led_var.ledValue = led.cycle(led_var.ledValue, 0, 255);
        ledcWrite(0, led_var.ledValue);
      }
    }
  #elif defined(ARDUINO_TINYPICO)
    if (battery.percentage < 10) {                // low battery (red)
      led.setInterval(20);
      led_var.color = led.blink(255, 20);
      tinypico.DotStar_SetPixelColor(led_var.color, 0, 0);
    } else {
      if (puara.get_StaIsConnected()) {         
        led.setInterval(1000);                // RGB: 0, 128, 255
       // (Dodger Blue) 
        led_var.color = led.blink(255,20);
        tinypico.DotStar_SetPixelColor(0, uint8_t(led_var.color/2),
               led_var.color);
    } else {
        led.setInterval(4000);
        led_var.color = led.cycle(led_var.color, 0, 255);
        tinypico.DotStar_SetPixelColor(0, uint8_t(led_var.color/2),
            led_var.color);
      }
    }
  #endif

  // run at 100 Hz
  vTaskDelay(10 / portTICK_PERIOD_MS);
}

void readBattery() {
#ifdef ARDUINO_LOLIN_D32_PRO
  battery.value =
      analogRead(pin.battery) / ADC12BIT_MAX * VOLTAGE_DIVIDER_RATIO;
#elif defined(ARDUINO_TINYPICO)
  battery.value = tinypico.GetBatteryVoltage();
#endif
  /*
   * Calculate battery percentage based on voltage, assuming linear discharge
   * between empty and full voltage levels. This simplification may not reflect
   * actual battery discharge curves but provides useful approximation for
   * monitoring battery status.
   *The percentage is clamped between 0% and 100% to avoid unrealistic values
   * due to measurement noise or voltage fluctuations.
   */
  battery.percentage = static_cast<int>(
      (battery.value - ASSUMED_EMPTY_BATTERY_VOLTAGE) * 100 /
      (ASSUMED_FULL_BATTERY_VOLTAGE - ASSUMED_EMPTY_BATTERY_VOLTAGE));

  if (battery.percentage > 100) {
    battery.percentage = 100;
  } else if (battery.percentage < 0) {
    battery.percentage = 0;
  }
}

void batteryFilter() {
  battery.filterArray.push_back(battery.percentage);
  if (battery.filterArray.size() > battery.queueAmount) {
    battery.filterArray.pop_front();
  }
  battery.percentage = 0;
  for (int i = 0; i < battery.filterArray.size(); i++) {
    battery.percentage += battery.filterArray.at(i);
  }
  battery.percentage /= battery.filterArray.size();
}

#ifndef Arduino_h
extern "C" {
void app_main(void);
}

void app_main() {
  setup();
  while (1) {
    loop();
  }
}
#endif

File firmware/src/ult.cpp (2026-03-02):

/* GuitarAMI Ultrassonic Sensor cpp file
 * Input Devices and Music Interaction Laboratory (IDMIL), McGill University
 * Edu Meneses (2022) - https://www.edumeneses.com
 */

#include "ult.h"

UltData ult;

int initUlt(int trig, int echo) {
    pinMode(trig, OUTPUT); // Sets the trigger pin as an OUTPUT
    pinMode(echo, INPUT); // Sets the echo pin as an INPUT
    ult.trig = trig;
    ult.echo = echo;
    return 1;
}

void readUlt() {
    if (millis() - ult.interval > ult.timer) {
        ult.lastDistance = ult.tempDistance;
        digitalWrite(ult.trig, LOW);
        delayMicroseconds(2);
        // Sets the trigger pin HIGH (ACTIVE) for 10 microseconds
        digitalWrite(ult.trig, HIGH);
        delayMicroseconds(10);
        digitalWrite(ult.trig, LOW);
        // Reads the echo pin, returns the sound wave travel time in microseconds
        ult.duration = pulseIn(ult.echo, HIGH);
        // Calculating the distance in mm
        ult.tempDistance = ult.duration * 0.34 / 2;
        if (ult.tempDistance < ult.ultMinDistance || ult.tempDistance > ult.ultMaxDistance) {
            ult.distance = 0;
        } else {
            ult.distance = ult.tempDistance;
        }
        if (ult.lastDistance == 0) {
            ult.trigTimer = millis();
            if (ult.tempDistance == 0) {
                ult.distance = 0;
                ult.trigger = 0;
            } 
        } else {
            if (millis() - ult.trigInterval > ult.trigTimer) {
                ult.distance = ult.tempDistance;
                ult.trigger = 0;
            } else if (ult.tempDistance == 0 && ult.distance != 0) {
                ult.trigger = 1;
            }
        }
        ultFilter();
        ult.timer = millis();
    }
}

void ultFilter() {
  ult.filterArray.push_back(ult.distance);
  if(ult.filterArray.size() > ult.queueAmount) {
    ult.filterArray.pop_front();
  }
  ult.distance = 0;
  for (int i=0; i<ult.filterArray.size(); i++) {
    ult.distance += ult.filterArray.at(i);
  }
  ult.distance /= ult.filterArray.size();
}

int getUltTrigger() {
    return ult.trigger;
}


int getUltDistance() {
    return ult.distance;
}

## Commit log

2021-06-03 firmware 210518
    [GuitarAMI_module_003_TinyPICO_RCWL1601_box_top.stl, GuitarAMI_module_005_TinyPICO_RCWL1601_box_top.stl, GuitarAMI_module_006_TinyPICO_RCWL1601_box_top.stl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]
2022-03-02 add M5StickC GuitarAMI firmware
    [min_spiffs.csv]
2022-04-27 added to Puara framewwork
    [GuitarAMI_module_003_TinyPICO_RCWL1601_box_top.stl, GuitarAMI_module_005_TinyPICO_RCWL1601_box_top.stl, GuitarAMI_module_006_TinyPICO_RCWL1601_box_top.stl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]
2022-09-09 fix ypr and touch
    [main.cpp]
2022-09-09 update pure data tester and delete old firmware folder
    [min_spiffs.csv]
2026-02-17 update to puara-module 1.0.1
    [min_spiffs.csv]
2026-02-27 added legacy esp f() to update touch_pad_set_thresh() so touch_sensitivity can really be implemented, repaired button logic from touch sensor and tap, db tap, tp tap all work properly now
2026-02-27 WIP: tinypico helper update and button(sensor.touch) and touch.getValue() management
2026-02-27 updated tinypico helper to 1.5 and cleaned battery related functions, everythng compiles and OSC messages send battery percentage and individualized button tags for clarity's sake
